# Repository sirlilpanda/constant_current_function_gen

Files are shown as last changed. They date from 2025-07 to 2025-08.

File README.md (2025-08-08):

# kicad project constant_current_function_gen


a cool table showing the workflow of all the kicad projects.
| project_name | DRC | ERC |
| --- | --- | --- |
| current_gen_class_ab | [❌](https://github.com/sirlilpanda/constant_current_function_gen/actions/runs/16821990167/attempts/1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)| [❌](https://github.com/sirlilpanda/constant_current_function_gen/actions/runs/16821990167/attempts/1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) | 
| current_gen | [✅](https://github.com/sirlilpanda/constant_current_function_gen/actions/runs/16821990167/attempts/1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)| [✅](https://github.com/sirlilpanda/constant_current_function_gen/actions/runs/16821990167/attempts/1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) | 

for a quick guide check [project setup](#project-setup)

This is a simple project template for new kicad projects. This template has some basic setup already completed such as workflows for auto creating all the things you forget when creating a kicad project such as:

| project_name | schematic | bom | bom report | gerbers |
| --- | --- | --- | --- | --- |
| [current_gen_class_ab](https://github.com/sirlilpanda/constant_current_function_gen/tree/main/./Hardware/current_gen_class_ab) | [current_gen_class_ab_schematic.pdf](https://github.com/sirlilpanda/constant_current_function_gen/tree/main/current_gen_class_ab_schematic.pdf) | [current_gen_class_ab_bill_of_materials.csv](https://github.com/sirlilpanda/constant_current_function_gen/tree/main/current_gen_class_ab_bill_of_materials.csv) | [current_gen_class_ab_bom_report.md](https://github.com/sirlilpanda/constant_current_function_gen/tree/main/current_gen_class_ab_bom_report.md) | [current_gen_class_ab_grbr.zip](https://github.com/sirlilpanda/constant_current_function_gen/tree/main/current_gen_class_ab_gerber.zip) |
| [current_gen](https://github.com/sirlilpanda/constant_current_function_gen/tree/main/./Hardware/current_gen) | [current_gen_schematic.pdf](https://github.com/sirlilpanda/constant_current_function_gen/tree/main/current_gen_schematic.pdf) | [current_gen_bill_of_materials.csv](https://github.com/sirlilpanda/constant_current_function_gen/tree/main/current_gen_bill_of_materials.csv) | [current_gen_bom_report.md](https://github.com/sirlilpanda/constant_current_function_gen/tree/main/current_gen_bom_report.md) | [current_gen_grbr.zip](https://github.com/sirlilpanda/constant_current_function_gen/tree/main/current_gen_gerber.zip) |

This workflow will also run the design rules check on the PCB and schematic to ensure that you upload a working PCB. These reports are uploaded as summaries within the github [actions tab](https://github.com/sirlilpanda/constant_current_function_gen/actions/runs/16821990167). This template has a simple schematic PCB in it (because DRC fails on an empty PCB). Shown below is the example PCB.

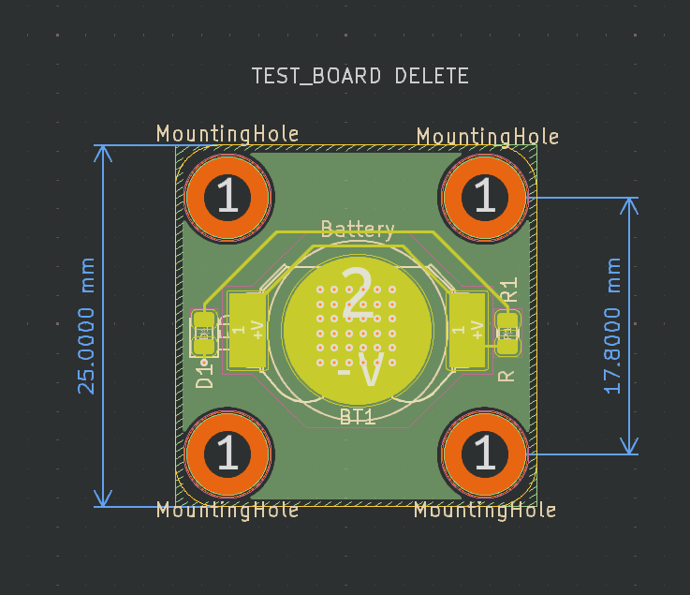
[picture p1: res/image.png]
example pcb with battery diode and resistor


besides from that the project also has:

- common predefined trace widths
- smallest vias size [JLCPBC allows](https://jlcpcb.com/capabilities/Capabilities#Drilling)
- custom net colours in the schematic editor
    - `red` for +V
    - `blue` for -V
    - `grey` for ground

to create a repo from this template follow this [guide](https://docs.github.com/en/repositories/creating-and-managing-repositories/creating-a-repository-from-a-template)

contained in this template are:
---
- `.github/` : all files relating to github actions and other admin see [here](https://docs.github.com/en/communities/setting-up-your-project-for-healthy-contributions) for more example of what can be placed in it
    - `report_processing` : where the python scripts are stored for processing the json report data from kicad
    - `report_templates` : where the template for said reports are stored
    - `workflows/` : this is where the github actions are kept
        - `main.yaml` : the main github action that will auto generate all files required and run DRC and ERC
    - `rename.py` : the script for renaming the project
- `hardware/` : this is where the kicad projects live note this can be changed
- `docs/` : this is where the generate docs are placed by default
    - `BOM/`     : where the bill of materials and price breakdown are kept
        - `bill_of_materials.csv`: the auto generated bom for the kicad project
        - `bom_report.md` : a report for the bill of materials
    - `template_schematic.pdf` : the schematic for the kicad project, auto generated by the github action
- `pcbs/` : this is where the auto generated gerbers for the kicad project are stored

- `res/` : where resources are stored for the README

- `.gitignore`: a slightly modified gitignore from the [standard one](https://github.com/github/gitignore/blob/main/KiCad.gitignore)

- `project_settings.yaml` : where the settings for this project is stored

- `README.md` : this file, suggest you change this one creating your project

## project settings
there are currently very few project settings that can be changed (will will be change in the future) these are:
| setting | description |
| --- | --- |
| has_been_set_up | a flag to tell the setup action if the project has been set up |
| project_name | the name of the project, this will be set to the name of the repo |
| production_formats | the output production format for the PCBs |
| dynamic_read_me | allow the readme to be updated using the given template |
| bom_template_path | the template used to write the bom report files |
| erc_report_template_path | the template used to write the erc report files |
| drc_report_template_path | the template used to write the drc report files |
| readme_template_path | the template used to write projects readme |
| schematic_output_name | the name suffix of the generated schematics |
| bom_csv_output_name | the name suffix of the generated bom csv file |
| bom_report_output_name | the name suffix of the generated bom report |
| production_file_output_name | the name suffix of the generated production file |
| schematic_output_path | the output path of the generated schematics files |
| bom_csv_output_path | the output path of the generated bom csv file |
| bom_report_output_path | the output path of the generated bom report |
| production_file_output_path | the output path of the generated production file |

## project setup

### creating a new repo with the template

creating a new template from a repo is simple:

1. click on the button in the top right hand corner called `use this template`
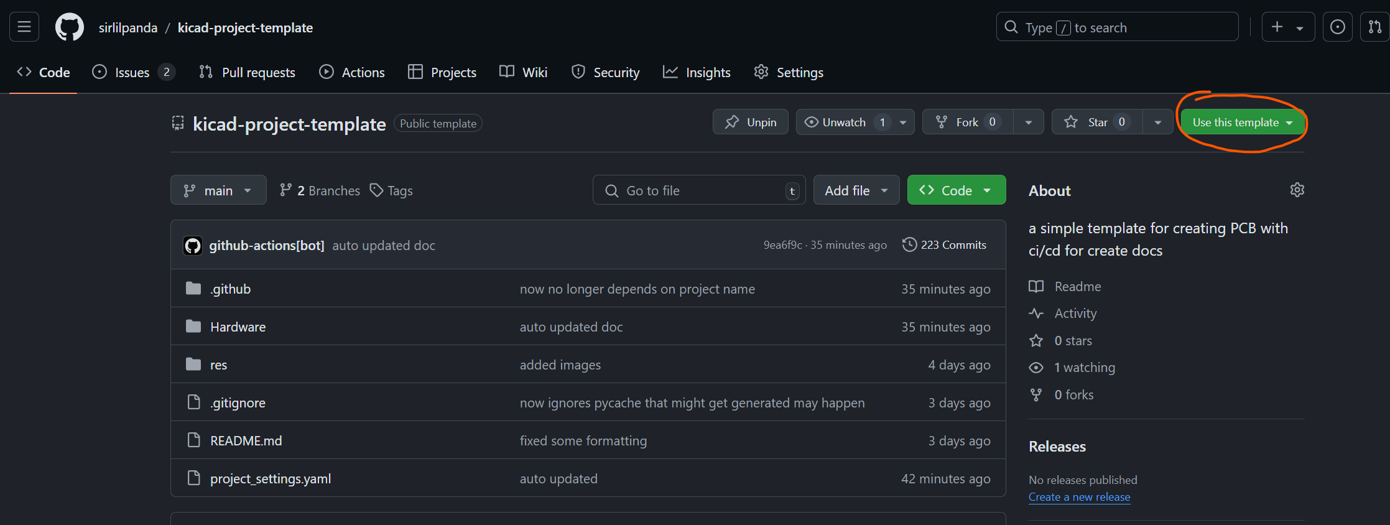
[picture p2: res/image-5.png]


2. when the drop down menu appears click on `create a new repository`
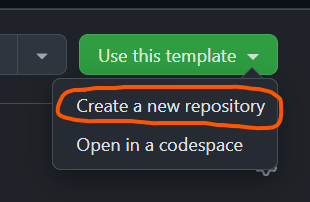
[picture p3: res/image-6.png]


3. once you click you will be brought to this page, note that the repo name you choose here will be the name that you kicad project is called.
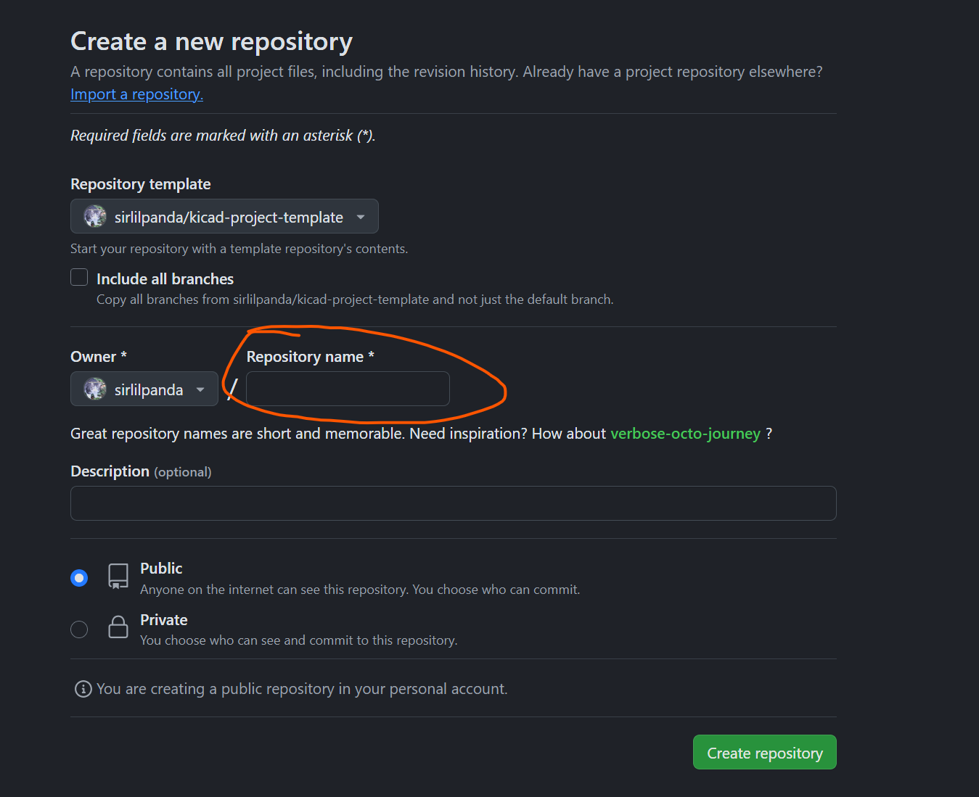
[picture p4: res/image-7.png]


after these steps you then need to configure the repo settings to do their magic see [configuring repo settings](#configuring-repo-settings) for what to do next.

### configuring repo settings

once you have created a new repo with the template, you ill have to configure the github action settings. this is because you will get an error that looks something along these lines:
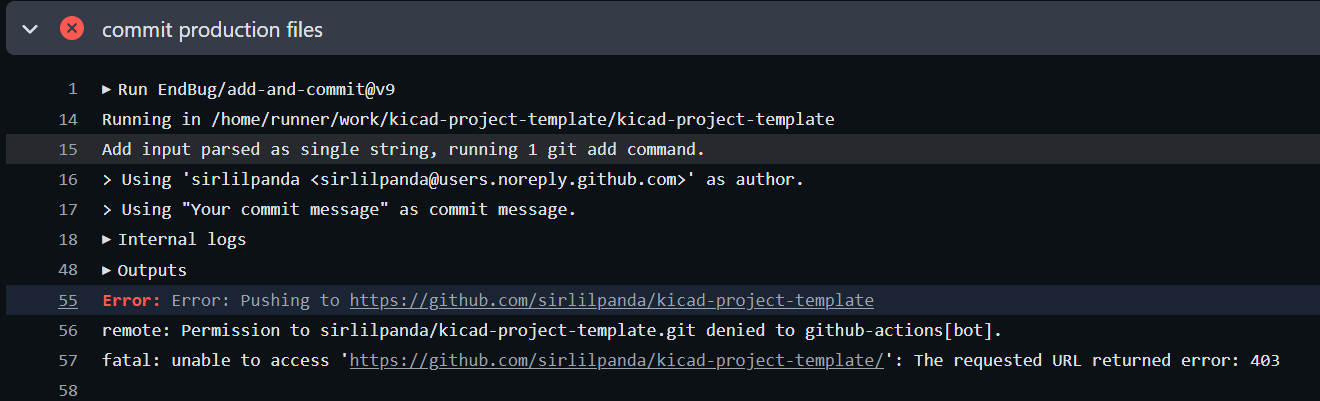
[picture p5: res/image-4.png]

where the action can not commit the changes due to not having permissions follow these steps:
1. open the repo setting
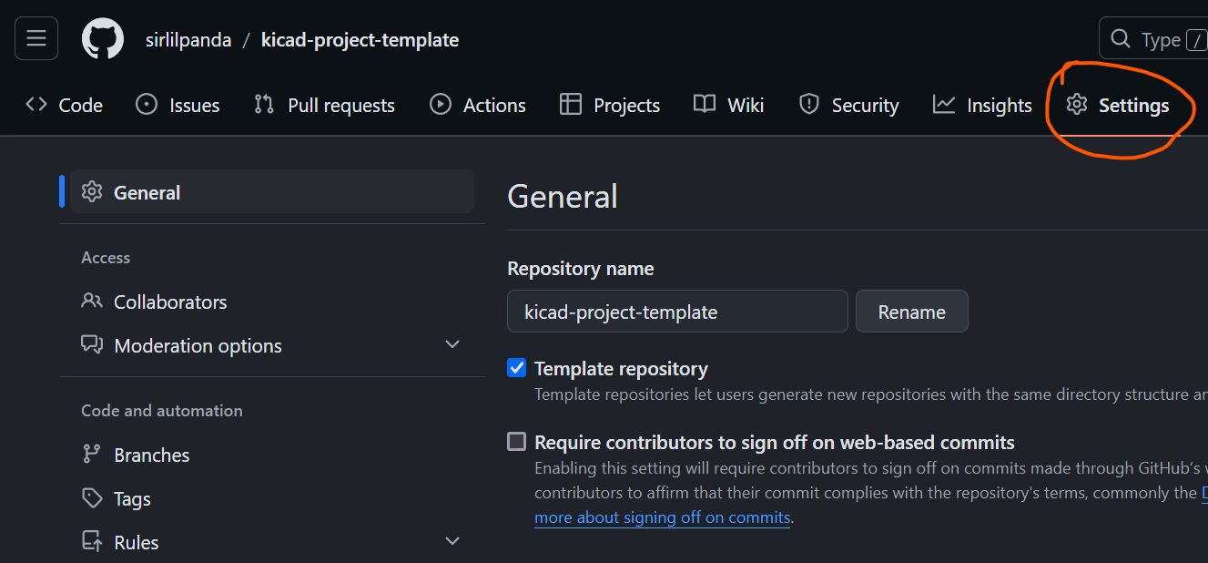
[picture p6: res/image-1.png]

2. then head in to actions : General
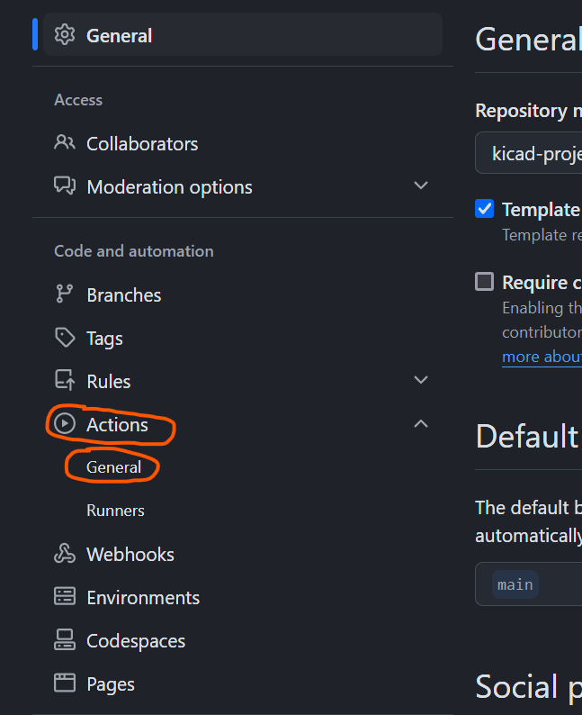
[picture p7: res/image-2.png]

3. then scroll down to workflow permissions and ensure that both
    `Read and write permissions` and `Allow GitHub Actions to create and approve pull requests` are ticked as seen below
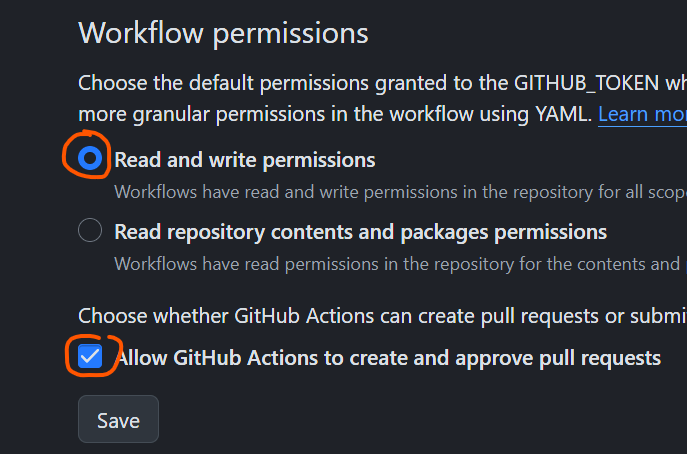
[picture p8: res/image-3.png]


this should fix the problem if not, go harass stack overflow they need it
Once all of these steps have been followed the workflow should be passing, however the `README.md` will only update on the next push request.

## editing the readme

As this repo can and will automatically update the repo corresponding to the given readme template. If you dont want to use this you can always disable this by setting the `dynamic_read_me` to `false`. but if you want some very cool features like auto updating tables to show what projects are passing the rules check or simple links to parts of your directory. then have a look at the template readme and learn [mustache](https://mustache.github.io/)

## improvements

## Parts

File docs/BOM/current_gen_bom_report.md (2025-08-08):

# 📄 BOM for current_gen_bill_of_material 📄

report created at 04:35:27.789618 on 08-08-2025.

current_gen_bill_of_material has a total of 28 parts with a cost of $0.

| Reference | Value | Quantity | part number | cost |
| --- | ----- | --- | --- | ---- |
| C1 | 1u | 1 |  | $0 |
| D1 | BZT52Bxx | 1 | Diode_SMD:D_SOD-123F | $0 |
| F1 | Fuse | 1 |  | $0 |
| J1 | Conn_Coaxial | 1 |  | $0 |
| J2 | Conn_Coaxial | 1 |  | $0 |
| J3 | Jack-DC | 1 |  | $0 |
| J4 | Conn_Coaxial | 1 |  | $0 |
| JP1 | Jumper_2_Open | 1 |  | $0 |
| Q1 | NPN | 1 |  | $0 |
| Q2 | NPN | 1 |  | $0 |
| Q3 | NPN | 1 |  | $0 |
| Q4 | NPN | 1 |  | $0 |
| Q5 | NPN | 1 |  | $0 |
| Q6 | NPN | 1 |  | $0 |
| Q7 | NPN | 1 |  | $0 |
| Q8 | NPN | 1 |  | $0 |
| Q9 | NPN | 1 |  | $0 |
| Q10 | NPN | 1 |  | $0 |
| Q11 | NPN | 1 |  | $0 |
| Q12 | NPN | 1 |  | $0 |
| Q13 | BSP129 | 1 | Package_TO_SOT_SMD:SOT-223-3_TabPin2 | $0 |
| R1 | 100R | 1 |  | $0 |
| R2 | 330R | 1 |  | $0 |
| R3 | 22R | 1 |  | $0 |
| R4 | 1k | 1 |  | $0 |
| R5 | 10k | 1 |  | $0 |
| R6 | 10m | 1 |  | $0 |
| U1 | OPA2673 | 1 | Package_DFN_QFN:Texas_RSA_VQFN-16-1EP_4x4mm_P0.65mm_EP2.7x2.7mm | $0 |
|  | total | 28 | total | $0 |

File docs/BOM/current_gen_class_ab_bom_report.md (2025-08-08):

# 📄 BOM for current_gen_class_ab_bill_of_material 📄

report created at 04:35:23.391193 on 08-08-2025.

current_gen_class_ab_bill_of_material has a total of 67 parts with a cost of $0.

| Reference | Value | Quantity | part number | cost |
| --- | ----- | --- | --- | ---- |
| C1 | 1u | 1 | Capacitor_SMD:C_0805_2012Metric | $0 |
| C2 | 1u | 1 | Capacitor_SMD:C_0805_2012Metric | $0 |
| C3 | 1u | 1 | Capacitor_SMD:C_0805_2012Metric | $0 |
| C4 | 1u | 1 | Capacitor_SMD:C_0805_2012Metric | $0 |
| C5 | 1u | 1 | Capacitor_SMD:C_0805_2012Metric | $0 |
| D1 | D_Zener | 1 | Diode_SMD:D_SOD-123 | $0 |
| D2 | D_Zener | 1 | Diode_SMD:D_SOD-123 | $0 |
| D3 | BAV99 | 1 | Package_TO_SOT_SMD:SOT-23 | $0 |
| D4 | LED | 1 | Diode_SMD:D_0603_1608Metric | $0 |
| D5 | LED | 1 | Diode_SMD:D_0603_1608Metric | $0 |
| D6 | LED | 1 | Diode_SMD:D_0603_1608Metric | $0 |
| D7 | LED | 1 | Diode_SMD:D_0603_1608Metric | $0 |
| F1 | Fuse | 1 | Fuse:Fuseholder_Clip-5x20mm_Bel_FC-203-22_Lateral_P17.80x5.00mm_D1.17mm_Horizontal | $0 |
| F2 | Fuse | 1 | Fuse:Fuseholder_Clip-5x20mm_Bel_FC-203-22_Lateral_P17.80x5.00mm_D1.17mm_Horizontal | $0 |
| F4 | Fuse | 1 | Fuse:Fuseholder_Clip-5x20mm_Bel_FC-203-22_Lateral_P17.80x5.00mm_D1.17mm_Horizontal | $0 |
| F5 | Fuse | 1 | Fuse:Fuseholder_Clip-5x20mm_Bel_FC-203-22_Lateral_P17.80x5.00mm_D1.17mm_Horizontal | $0 |
| J1 | Conn_Coaxial | 1 | Connector_Coaxial:BNC_TEConnectivity_1478035_Horizontal | $0 |
| J2 | Conn_Coaxial | 1 | Connector_Coaxial:BNC_TEConnectivity_1478035_Horizontal | $0 |
| J3 | Conn_01x01_Socket | 1 | Connector:Banana_Jack_1Pin | $0 |
| J4 | Conn_01x01_Socket | 1 | Connector:Banana_Jack_1Pin | $0 |
| J5 | Conn_01x01_Socket | 1 | Connector:Banana_Jack_1Pin | $0 |
| J6 | Conn_01x01_Socket | 1 | Connector:Banana_Jack_1Pin | $0 |
| J7 | Conn_01x01_Socket | 1 | Connector:Banana_Jack_1Pin | $0 |
| JP1 | Jumper_2_Open | 1 | Jumper:SolderJumper-2_P1.3mm_Open_TrianglePad1.0x1.5mm | $0 |
| JP2 | Jumper_2_Open | 1 | Jumper:SolderJumper-2_P1.3mm_Open_TrianglePad1.0x1.5mm | $0 |
| JP3 | Jumper_2_Open | 1 | Jumper:SolderJumper-2_P1.3mm_Open_TrianglePad1.0x1.5mm | $0 |
| JP4 | Jumper_2_Open | 1 | Jumper:SolderJumper-2_P1.3mm_Open_TrianglePad1.0x1.5mm | $0 |
| JP5 | Jumper_2_Open | 1 | Jumper:SolderJumper-2_P1.3mm_Open_TrianglePad1.0x1.5mm | $0 |
| Q1 | PMOS | 1 | Package_TO_SOT_THT:TO-220-3_Horizontal_TabDown | $0 |
| Q2 | NMOS | 1 | Package_TO_SOT_THT:TO-220-3_Horizontal_TabDown | $0 |
| Q3 | NMOS | 1 | Package_TO_SOT_THT:TO-220-3_Horizontal_TabDown | $0 |
| Q4 | PMOS | 1 | Package_TO_SOT_THT:TO-220-3_Horizontal_TabDown | $0 |
| R1 | 50 | 1 | Resistor_THT:R_Axial_DIN0309_L9.0mm_D3.2mm_P12.70mm_Horizontal | $0 |
| R2 | 92k | 1 | Resistor_SMD:R_0603_1608Metric | $0 |
| R3 | 92k | 1 | Resistor_SMD:R_0603_1608Metric | $0 |
| R4 | 100k | 1 | Resistor_SMD:R_0603_1608Metric | $0 |
| R5 | 1k | 1 | Resistor_SMD:R_0603_1608Metric | $0 |
| R6 | 1k | 1 | Resistor_SMD:R_0603_1608Metric | $0 |
| R7 | 100k | 1 | Resistor_SMD:R_0603_1608Metric | $0 |
| R8 | 100k | 1 | Resistor_SMD:R_0603_1608Metric | $0 |
| R9 | 1k | 1 | Resistor_SMD:R_0603_1608Metric | $0 |
| R10 | 1k | 1 | Resistor_SMD:R_0603_1608Metric | $0 |
| R11 | 100k | 1 | Resistor_SMD:R_0603_1608Metric | $0 |
| R12 | 92k | 1 | Resistor_SMD:R_0603_1608Metric | $0 |
| R13 | 92k | 1 | Resistor_SMD:R_0603_1608Metric | $0 |
| R14 | 10 | 1 | Resistor_SMD:R_0603_1608Metric | $0 |
| R15 | 10 | 1 | Resistor_SMD:R_0603_1608Metric | $0 |
| R16 | 5R | 1 | Package_TO_SOT_THT:TO-220-2_Horizontal_TabDown | $0 |
| R17 | 5R | 1 | Package_TO_SOT_THT:TO-220-2_Horizontal_TabDown | $0 |
| R18 | 10k | 1 | Potentiometer_THT:Potentiometer_Bourns_3296W_Vertical | $0 |
| R19 | 10k | 1 | Potentiometer_THT:Potentiometer_Bourns_3296W_Vertical | $0 |
| R20 | 92k | 1 | Resistor_SMD:R_0603_1608Metric | $0 |
| R21 | 92k | 1 | Resistor_SMD:R_0603_1608Metric | $0 |
| R22 | 1k | 1 | Resistor_SMD:R_0603_1608Metric | $0 |
| R23 | 1k | 1 | Resistor_SMD:R_0603_1608Metric | $0 |
| R24 | 1k | 1 | Resistor_SMD:R_0603_1608Metric | $0 |
| R25 | 27k | 1 | Resistor_SMD:R_0603_1608Metric | $0 |
| R26 | 1k | 1 | Resistor_SMD:R_0603_1608Metric | $0 |
| R27 | 27k | 1 | Resistor_SMD:R_0603_1608Metric | $0 |
| R28 | 1k | 1 | Resistor_SMD:R_0603_1608Metric | $0 |
| R29 | 1k | 1 | Resistor_SMD:R_0603_1608Metric | $0 |
| RV1 | 10k | 1 | footprints:POT_P120PK-x25_TTE | $0 |
| RV2 | 10k | 1 | footprints:POT_P120PK-x25_TTE | $0 |
| RV3 | 10k | 1 | Potentiometer_THT:Potentiometer_Bourns_PTV09A-1_Single_Vertical | $0 |
| RV4 | 10k | 1 | Potentiometer_THT:Potentiometer_Bourns_PTV09A-1_Single_Vertical | $0 |
| U1 | Opamp_Dual | 1 | Package_SO:SOIC-8-1EP_3.9x4.9mm_P1.27mm_EP2.29x3mm_ThermalVias | $0 |
| U2 | Opamp_Dual | 1 | Package_SO:SOIC-8-1EP_3.9x4.9mm_P1.27mm_EP2.29x3mm_ThermalVias | $0 |
|  | total | 67 | total | $0 |

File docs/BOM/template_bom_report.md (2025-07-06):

# 📄 BOM for template_bill_of_material 📄

report created at 00:00:12.772009 on 02-07-2025.

template_bill_of_material has a total of 3 parts with a cost of $0.

| Reference | Value | Quantity | part number | cost |
| --- | ----- | --- | --- | ---- |
| BT1 | Battery | 1 | Battery:BatteryHolder_LINX_BAT-HLD-012-SMT | $0 |
| D1 | LED | 1 | LED_SMD:LED_0805_2012Metric | $0 |
| R1 | R | 1 | Resistor_SMD:R_0805_2012Metric | $0 |
|  | total | 3 | total | $0 |

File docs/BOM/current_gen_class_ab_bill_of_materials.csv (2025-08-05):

Refs | Value | Footprint | Qty | DNP
C1 | 1u | Capacitor_SMD:C_0805_2012Metric | 1
C2 | 1u | Capacitor_SMD:C_0805_2012Metric | 1
C3 | 1u | Capacitor_SMD:C_0805_2012Metric | 1
C4 | 1u | Capacitor_SMD:C_0805_2012Metric | 1
C5 | 1u | Capacitor_SMD:C_0805_2012Metric | 1
D1 | D_Zener | Diode_SMD:D_SOD-123 | 1
D2 | D_Zener | Diode_SMD:D_SOD-123 | 1
D3 | BAV99 | Package_TO_SOT_SMD:SOT-23 | 1
D4 | LED | Diode_SMD:D_0603_1608Metric | 1
D5 | LED | Diode_SMD:D_0603_1608Metric | 1
D6 | LED | Diode_SMD:D_0603_1608Metric | 1
D7 | LED | Diode_SMD:D_0603_1608Metric | 1
F1 | Fuse | Fuse:Fuseholder_Clip-5x20mm_Bel_FC-203-22_Lateral_P17.80x5.00mm_D1.17mm_Horizontal | 1
F2 | Fuse | Fuse:Fuseholder_Clip-5x20mm_Bel_FC-203-22_Lateral_P17.80x5.00mm_D1.17mm_Horizontal | 1
F4 | Fuse | Fuse:Fuseholder_Clip-5x20mm_Bel_FC-203-22_Lateral_P17.80x5.00mm_D1.17mm_Horizontal | 1
F5 | Fuse | Fuse:Fuseholder_Clip-5x20mm_Bel_FC-203-22_Lateral_P17.80x5.00mm_D1.17mm_Horizontal | 1
J1 | Conn_Coaxial | Connector_Coaxial:BNC_TEConnectivity_1478035_Horizontal | 1
J2 | Conn_Coaxial | Connector_Coaxial:BNC_TEConnectivity_1478035_Horizontal | 1
J3 | Conn_01x01_Socket | Connector:Banana_Jack_1Pin | 1
J4 | Conn_01x01_Socket | Connector:Banana_Jack_1Pin | 1
J5 | Conn_01x01_Socket | Connector:Banana_Jack_1Pin | 1
J6 | Conn_01x01_Socket | Connector:Banana_Jack_1Pin | 1
J7 | Conn_01x01_Socket | Connector:Banana_Jack_1Pin | 1
JP1 | Jumper_2_Open | Jumper:SolderJumper-2_P1.3mm_Open_TrianglePad1.0x1.5mm | 1
JP2 | Jumper_2_Open | Jumper:SolderJumper-2_P1.3mm_Open_TrianglePad1.0x1.5mm | 1
JP3 | Jumper_2_Open | Jumper:SolderJumper-2_P1.3mm_Open_TrianglePad1.0x1.5mm | 1
JP4 | Jumper_2_Open | Jumper:SolderJumper-2_P1.3mm_Open_TrianglePad1.0x1.5mm | 1
JP5 | Jumper_2_Open | Jumper:SolderJumper-2_P1.3mm_Open_TrianglePad1.0x1.5mm | 1
Q1 | PMOS | Package_TO_SOT_THT:TO-220-3_Horizontal_TabDown | 1
Q2 | NMOS | Package_TO_SOT_THT:TO-220-3_Horizontal_TabDown | 1
Q3 | NMOS | Package_TO_SOT_THT:TO-220-3_Horizontal_TabDown | 1
Q4 | PMOS | Package_TO_SOT_THT:TO-220-3_Horizontal_TabDown | 1
R1 | 50 | Resistor_THT:R_Axial_DIN0309_L9.0mm_D3.2mm_P12.70mm_Horizontal | 1
R2 | 92k | Resistor_SMD:R_0603_1608Metric | 1
R3 | 92k | Resistor_SMD:R_0603_1608Metric | 1
R4 | 100k | Resistor_SMD:R_0603_1608Metric | 1
R5 | 1k | Resistor_SMD:R_0603_1608Metric | 1
R6 | 1k | Resistor_SMD:R_0603_1608Metric | 1
R7 | 100k | Resistor_SMD:R_0603_1608Metric | 1
R8 | 100k | Resistor_SMD:R_0603_1608Metric | 1
R9 | 1k | Resistor_SMD:R_0603_1608Metric | 1
R10 | 1k | Resistor_SMD:R_0603_1608Metric | 1
R11 | 100k | Resistor_SMD:R_0603_1608Metric | 1
R12 | 92k | Resistor_SMD:R_0603_1608Metric | 1
R13 | 92k | Resistor_SMD:R_0603_1608Metric | 1
R14 | 10 | Resistor_SMD:R_0603_1608Metric | 1
R15 | 10 | Resistor_SMD:R_0603_1608Metric | 1
R16 | 5R | Package_TO_SOT_THT:TO-220-2_Horizontal_TabDown | 1
R17 | 5R | Package_TO_SOT_THT:TO-220-2_Horizontal_TabDown | 1
R18 | 10k | Potentiometer_THT:Potentiometer_Bourns_3296W_Vertical | 1
R19 | 10k | Potentiometer_THT:Potentiometer_Bourns_3296W_Vertical | 1
R20 | 92k | Resistor_SMD:R_0603_1608Metric | 1
R21 | 92k | Resistor_SMD:R_0603_1608Metric | 1
R22 | 1k | Resistor_SMD:R_0603_1608Metric | 1
R23 | 1k | Resistor_SMD:R_0603_1608Metric | 1
R24 | 1k | Resistor_SMD:R_0603_1608Metric | 1
R25 | 27k | Resistor_SMD:R_0603_1608Metric | 1
R26 | 1k | Resistor_SMD:R_0603_1608Metric | 1
R27 | 27k | Resistor_SMD:R_0603_1608Metric | 1
R28 | 1k | Resistor_SMD:R_0603_1608Metric | 1
R29 | 1k | Resistor_SMD:R_0603_1608Metric | 1
RV1 | 10k | footprints:POT_P120PK-x25_TTE | 1
RV2 | 10k | footprints:POT_P120PK-x25_TTE | 1
RV3 | 10k | Potentiometer_THT:Potentiometer_Bourns_PTV09A-1_Single_Vertical | 1
RV4 | 10k | Potentiometer_THT:Potentiometer_Bourns_PTV09A-1_Single_Vertical | 1
U1 | Opamp_Dual | Package_SO:SOIC-8-1EP_3.9x4.9mm_P1.27mm_EP2.29x3mm_ThermalVias | 1
U2 | Opamp_Dual | Package_SO:SOIC-8-1EP_3.9x4.9mm_P1.27mm_EP2.29x3mm_ThermalVias | 1

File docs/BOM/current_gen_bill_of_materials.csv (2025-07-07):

Refs | Value | Footprint | Qty | DNP
C1 | 1u |  | 1
D1 | BZT52Bxx | Diode_SMD:D_SOD-123F | 1
F1 | Fuse |  | 1
J1 | Conn_Coaxial |  | 1
J2 | Conn_Coaxial |  | 1
J3 | Jack-DC |  | 1
J4 | Conn_Coaxial |  | 1
JP1 | Jumper_2_Open |  | 1
Q1 | NPN |  | 1
Q2 | NPN |  | 1
Q3 | NPN |  | 1
Q4 | NPN |  | 1
Q5 | NPN |  | 1
Q6 | NPN |  | 1
Q7 | NPN |  | 1
Q8 | NPN |  | 1
Q9 | NPN |  | 1
Q10 | NPN |  | 1
Q11 | NPN |  | 1
Q12 | NPN |  | 1
Q13 | BSP129 | Package_TO_SOT_SMD:SOT-223-3_TabPin2 | 1
R1 | 100R |  | 1
R2 | 330R |  | 1
R3 | 22R |  | 1
R4 | 1k |  | 1
R5 | 10k |  | 1
R6 | 10m |  | 1
U1 | OPA2673 | Package_DFN_QFN:Texas_RSA_VQFN-16-1EP_4x4mm_P0.65mm_EP2.7x2.7mm | 1

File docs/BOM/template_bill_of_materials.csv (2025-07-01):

Refs | Value | Footprint | Qty | DNP
BT1 | Battery | Battery:BatteryHolder_LINX_BAT-HLD-012-SMT | 1
D1 | LED | LED_SMD:LED_0805_2012Metric | 1
R1 | R | Resistor_SMD:R_0805_2012Metric | 1

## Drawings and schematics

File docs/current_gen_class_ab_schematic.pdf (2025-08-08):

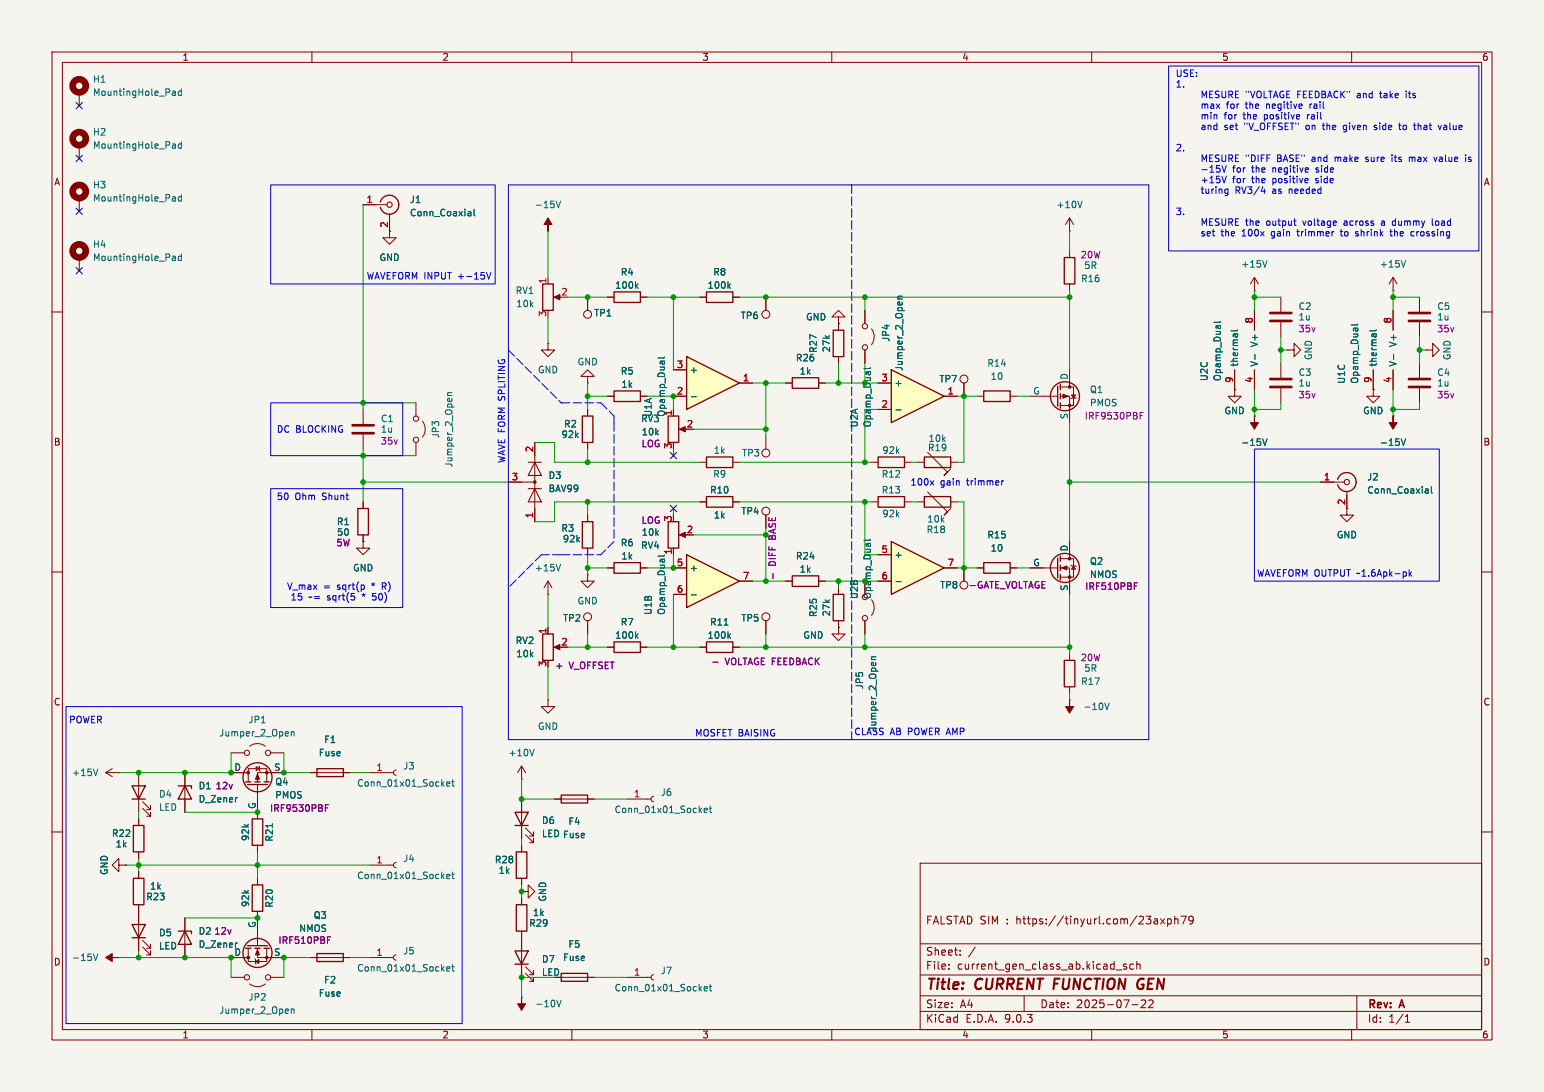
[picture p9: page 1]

CLASS AB POWER AMP

Id: 1/1 Title: CURRENT FUNCTION GEN

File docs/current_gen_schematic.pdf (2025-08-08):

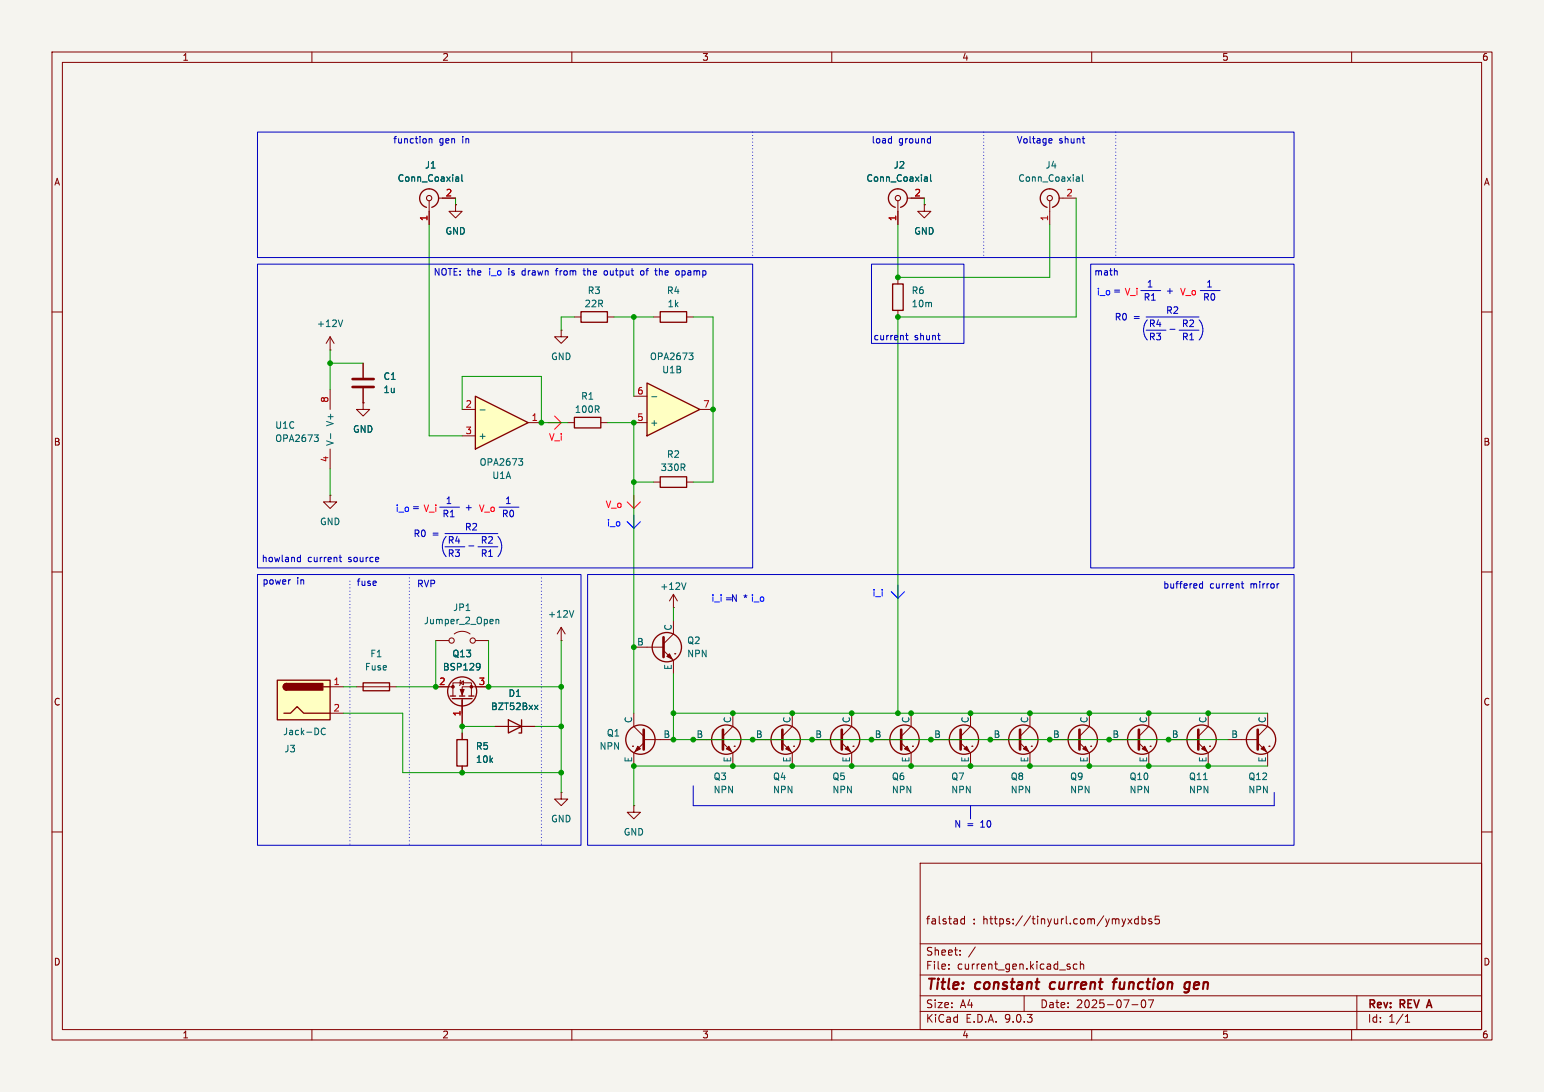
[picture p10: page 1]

File: current_gen.kicad_sch Sheet: /
Id: 1/1 Title: constant current function gen

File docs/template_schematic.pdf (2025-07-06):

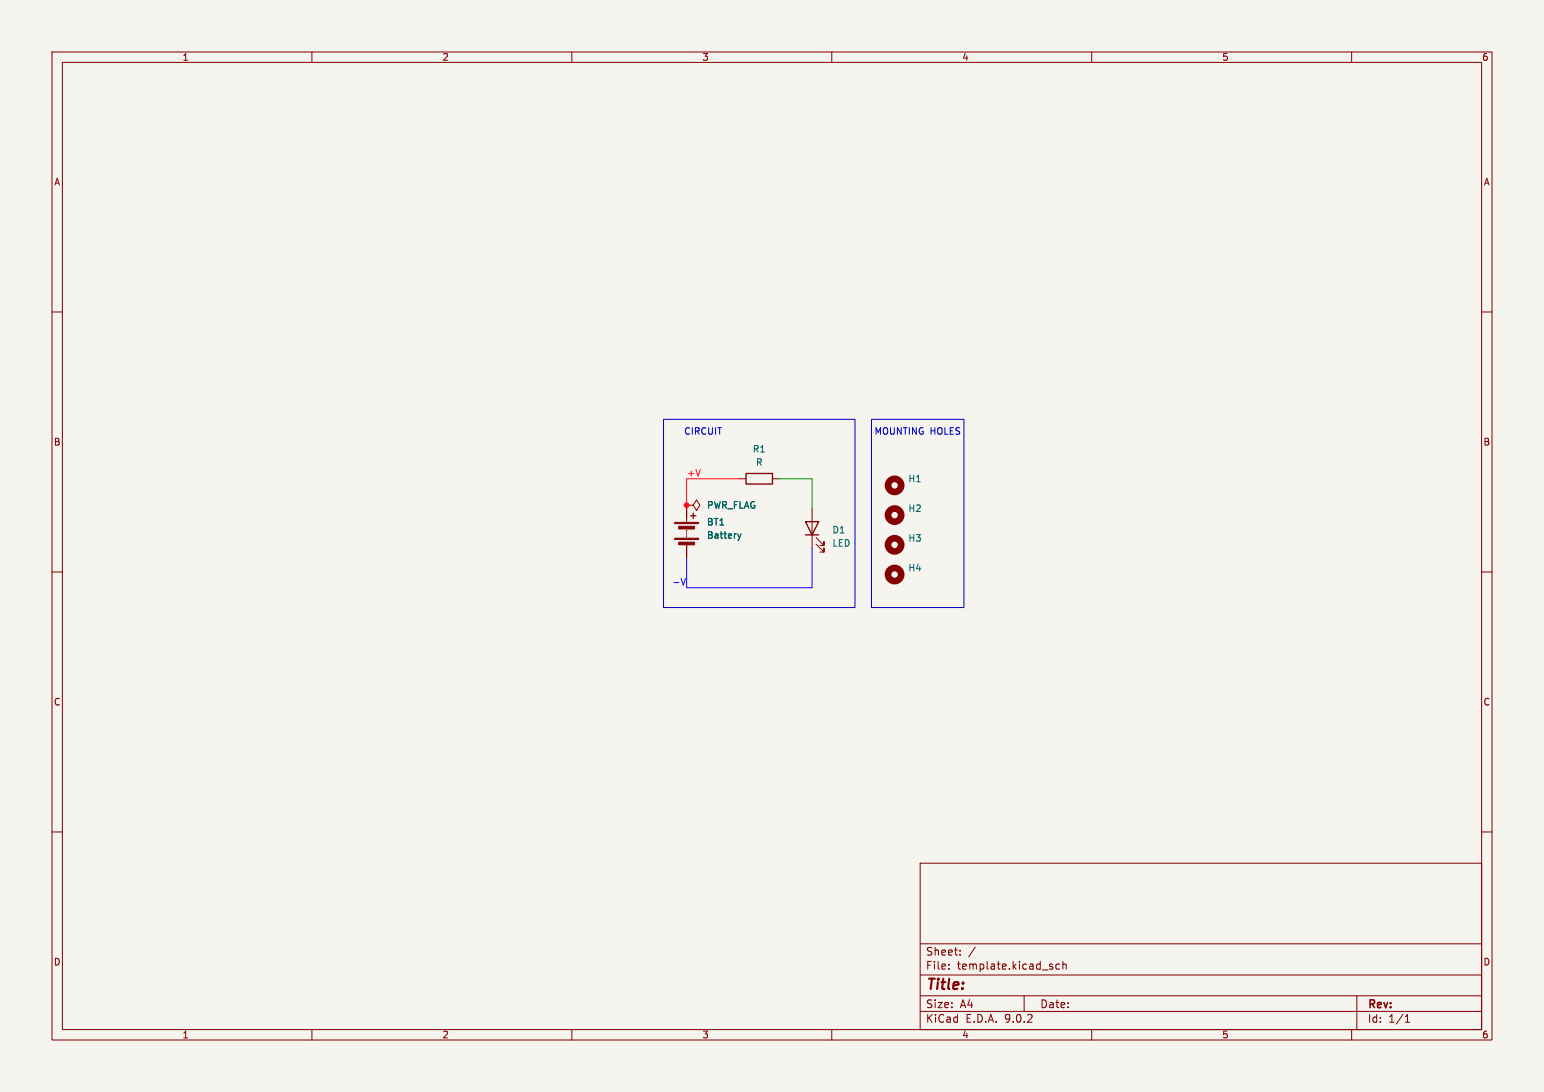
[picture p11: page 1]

Id: 1/1 Title: File: template.kicad_sch Sheet: / H4 D1
LED

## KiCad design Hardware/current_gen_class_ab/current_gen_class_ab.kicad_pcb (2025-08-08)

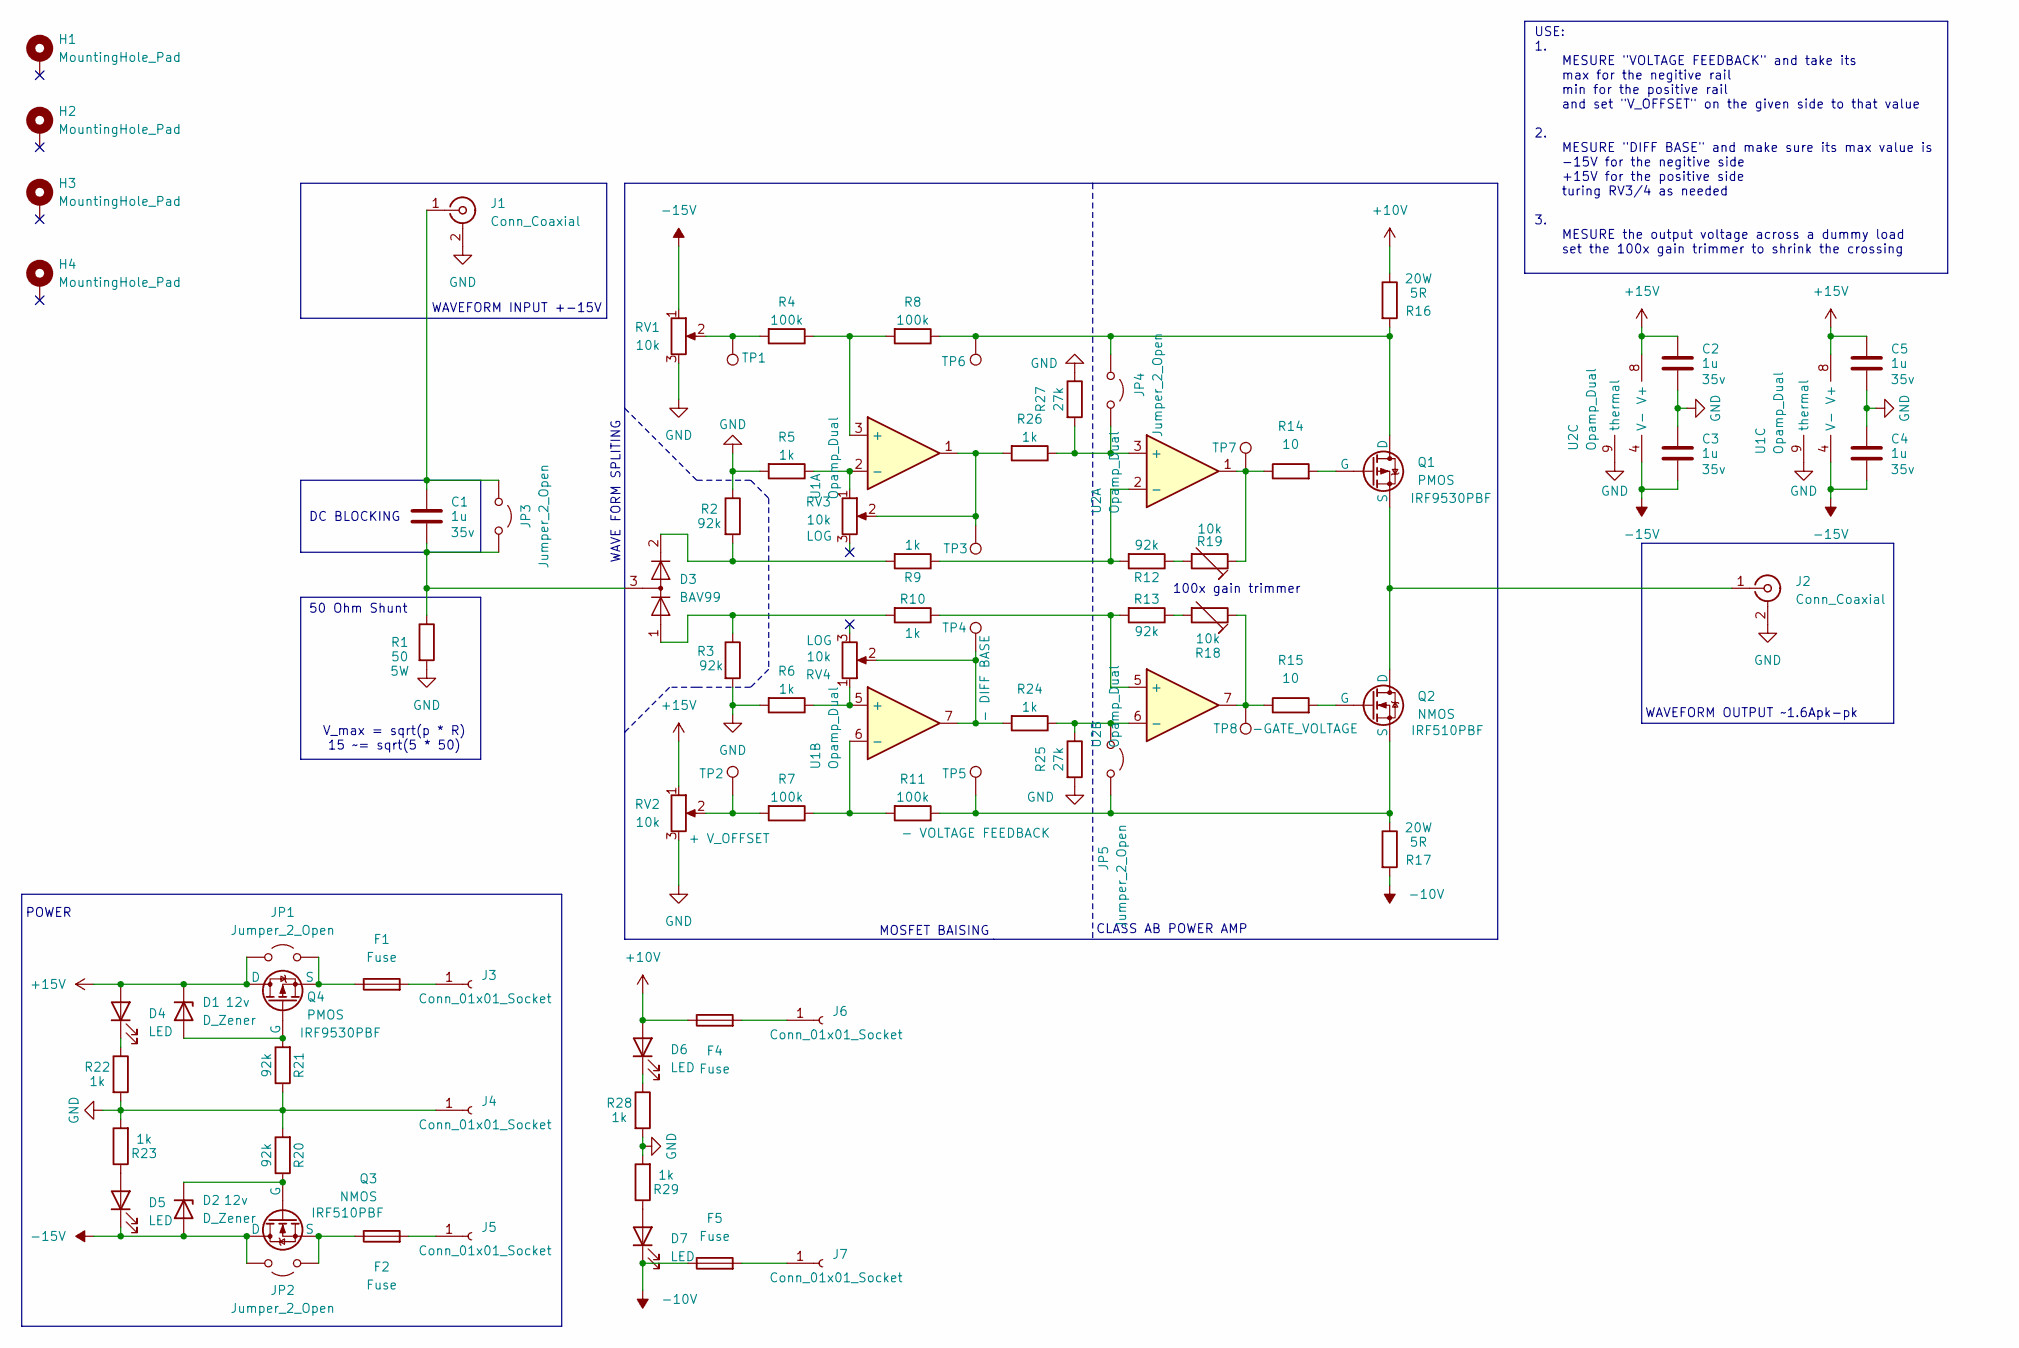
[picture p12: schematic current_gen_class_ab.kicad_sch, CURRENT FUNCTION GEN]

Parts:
C1, C2, C3, C4, C5: 1u; C_0805_2012Metric
D1, D2: D_Zener; D_SOD-123
D3: BAV99; SOT-23; Manufactor Part Number BAV99
D4, D5, D6, D7: LED; D_0603_1608Metric
F1, F2, F4, F5: Fuse; Fuseholder_Clip-5x20mm_Bel_FC-203-22_Lateral_P17.80x5.00mm_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
H1, H2, H3, H4: MountingHole_Pad; MountingHole_3.2mm_M3_DIN965_Pad
J1, J2: Conn_Coaxial; BNC_TEConnectivity_1478035_Horizontal
J3, J4, J5, J6, J7: Conn_01x01_Socket; Banana_Jack_1Pin
JP1, JP2, JP3, JP4, JP5: Jumper_2_Open; SolderJumper-2_P1.3mm_Open_TrianglePad1.0x1.5mm
Q1, Q4: PMOS; TO-220-3_Horizontal_TabDown
Q2, Q3: NMOS; TO-220-3_Horizontal_TabDown
R1: 50; R_Axial_DIN0309_L9.0mm_D3.2mm_P12.70mm_Horizontal
R2, R3, R12, R13, R20, R21: 92k; R_0603_1608Metric
R4, R7, R8, R11: 100k; R_0603_1608Metric
R5, R6, R9, R10, R22, R23, R24, R26, R28, R29: 1k; R_0603_1608Metric
R14, R15: 10; R_0603_1608Metric
R16, R17: 5R; TO-220-2_Horizontal_TabDown
R18, R19: 10k; Potentiometer_Bourns_3296W_Vertical
R25, R27: 27k; R_0603_1608Metric
RV1, RV2: 10k; POT_P120PK-x25_TTE
RV3, RV4: 10k; Potentiometer_Bourns_PTV09A-1_Single_Vertical
TP1, TP2, TP3, TP4, TP5, TP6, TP7, TP8: TestPoint; TestPoint_Bridge_Pitch2.54mm_Drill1.3mm
U1, U2: Opamp_Dual; SOIC-8-1EP_3.9x4.9mm_P1.27mm_EP2.29x3mm_ThermalVias

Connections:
+10V: D6.2 (A), F4.1, R16.1
+15V: C2.2, C5.2, D1.1 (K), D4.2 (A), JP1.1 (A), Q4.1 (D), RV2.1, U1.8 (V+), U2.8 (V+)
-10V: D7.1 (K), F5.1, R17.2
-15V: C3.1, C4.1, D2.2 (A), D5.1 (K), JP2.2 (B), Q3.1 (D), RV1.1, U1.4 (V-), U2.4 (V-)
GND: C2.1, C3.2, C4.2, C5.1, J1.2 (Ext), J2.2 (Ext), J4.1, R1.2, R2.1, R3.2, R5.2, R6.2, R20.2, R21.1, R22.2, R23.2, R25.2, R27.1, R28.2, R29.2, RV1.3, RV2.3, U1.9 (thermal), U2.9 (thermal)
unnamed: D1.2 (A), Q4.2 (G), R21.2
unnamed: D2.1 (K), Q3.2 (G), R20.1
unnamed: D3.2 (A), R2.2, R9.2
unnamed: D3.1 (K), R3.1, R10.2
unnamed: D4.1 (K), R22.1
unnamed: D5.2 (A), R23.1
unnamed: D6.1 (K), R28.1
unnamed: D7.2 (A), R29.1
unnamed: C1.2, J1.1 (In), JP3.1 (A)
unnamed: J2.1 (In), Q1.3 (S), Q2.1 (D)
unnamed: F1.2, J3.1
unnamed: F2.2, J5.1
unnamed: F4.2, J6.1
unnamed: F5.2, J7.1
unnamed: F1.1, JP1.2 (B), Q4.3 (S)
unnamed: F2.1, JP2.1 (A), Q3.3 (S)
unnamed: C1.1, D3.3 (K), JP3.2 (B), R1.1
unnamed: JP4.1 (A), Q1.1 (D), R8.1, R16.2, TP6.1
unnamed: JP4.2 (B), R26.1, R27.2, U2.3 (+)
unnamed: JP5.1 (A), R24.1, R25.1, U2.6 (-)
unnamed: JP5.2 (B), Q2.3 (S), R11.1, R17.1, TP5.1
unnamed: Q1.2 (G), R14.2
unnamed: Q2.2 (G), R15.2
unnamed: R4.2, RV1.2, TP1.1
unnamed: R7.2, RV2.2, TP2.1
unnamed: R12.1, R19.2
unnamed: R13.1, R18.2
unnamed: R14.1, R19.1, TP7.1, U2.1
unnamed: R15.1, R18.1, TP8.1, U2.7
unnamed: R24.2, RV4.2, TP4.1, U1.7
unnamed: R26.2, RV3.2, TP3.1, U1.1
unnamed: R4.1, R8.2, U1.3 (+)
unnamed: R5.1, RV3.1, U1.2 (-)
unnamed: R6.1, RV4.1, U1.5 (+)
unnamed: R7.1, R11.2, U1.6 (-)
unnamed: R9.1, R12.2, U2.2 (-)
unnamed: R10.1, R13.2, U2.5 (+)

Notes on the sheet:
MOSFET BAISING
WAVE FORM SPLITING
POWER
V_max = sqrt(p * R) 15 ~= sqrt(5 * 50)
WAVEFORM OUTPUT ~1.6Apk-pk
CLASS AB POWER AMP
100x gain trimmer
50 Ohm Shunt
DC BLOCKING
USE: 1. MESURE "VOLTAGE FEEDBACK" and take its max for the negitive rail min for the positive rail and set "V_OFFSET" on the given side to that value 2. MESURE "DIFF BASE" and make sure its max value is -15V for the negitive side +15V for the positive side turing RV3/4 as needed 3. MESURE the outpu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
WAVEFORM INPUT +-15V

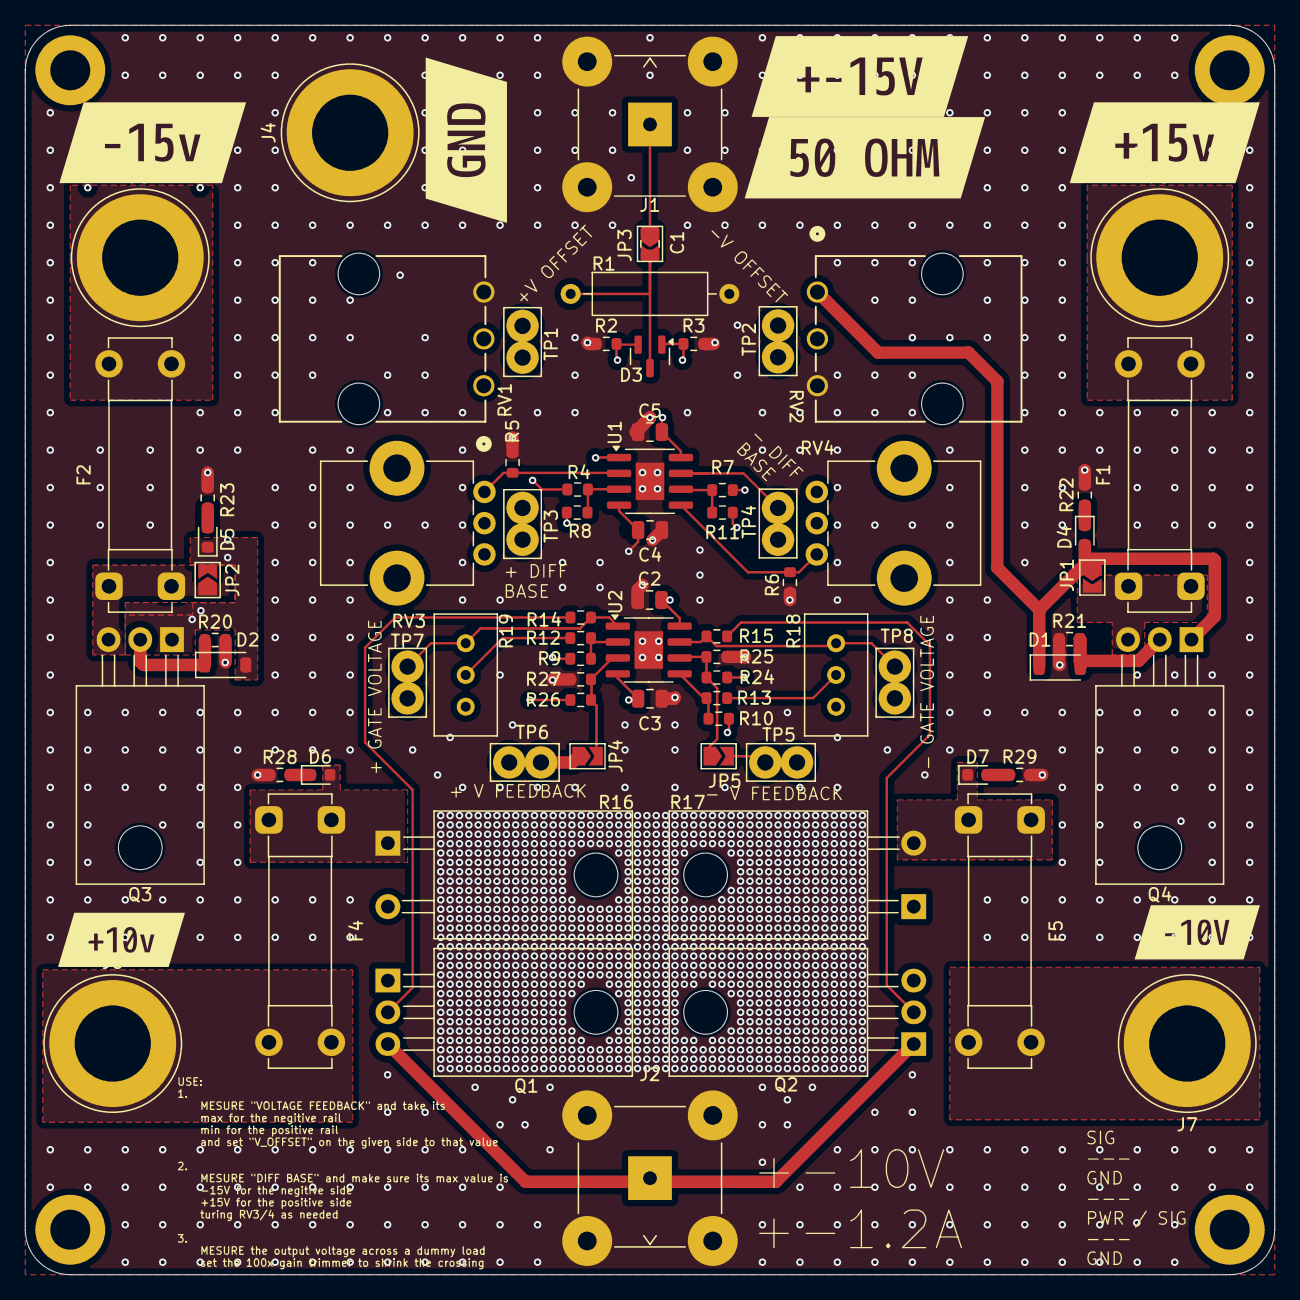
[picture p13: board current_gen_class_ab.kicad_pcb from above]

Board: 4 copper layers, 100.0 x 100.0 mm, 86 parts (0 on the bottom side), 42 nets.

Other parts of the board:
kibuzzard-68929C8D: G***; kibuzzard-68929C8D
kibuzzard-68929C33: G***; kibuzzard-68929C33
kibuzzard-68929C42: G***; kibuzzard-68929C42
kibuzzard-68929C79: G***; kibuzzard-68929C79
kibuzzard-68929C81: G***; kibuzzard-68929C81
kibuzzard-68929CA4: G***; kibuzzard-68929CA4
kibuzzard-68929CB0: G***; kibuzzard-68929CB0

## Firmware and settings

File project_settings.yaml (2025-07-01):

needs_setup: false

# this is set to the name of your repo during setup, you can change it later on using the rename tool
project_name: constant_current_function_gen 

# this is a list of the production formats that you would like
# honestly only use gerbers, i doubt i will add anything else
# but if you want something custom, implement it and throw in
# a pull request
#not support
production_format: gerber

schematic_output_path: docs/

bom_csv_output_path: docs/BOM/

bom_report_output_path: docs/BOM/

production_file_output_path: pcbs/

# all names will follow the pattern [project_name]name.* 
# these settings just define that name suffix
# the underscore here are purely for readablity of the
# output files so the schematic output file name will be
# project_name_schematic.pdf
schematic_output_name: _schematic

bom_csv_output_name: _bill_of_materials

bom_report_output_name: _bom_report

production_file_output_name: _gerber

# these templates use mustache (https://mustache.github.io/mustache.5.html)
# a logic less templating langauge for templating just about anything
bom_template_path: .github/report_templates/bom_report_template.mustache

erc_report_template_path: .github/report_templates/erc_report_template.mustache

drc_report_template_path: .github/report_templates/drc_report_template.mustache

readme_template_path: .github/report_templates/readme.mustache

# allow the readme to be auto updated using the readme template
dynamic_read_me: true

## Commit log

2025-07-06 added sch
    [current_gen.kicad_pcb, current_gen.kicad_sch, template.kicad_pcb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]
2025-07-06 production files
    [current_gen_bill_of_materials.csv]
2025-07-06 added shunt and rpv
    [current_gen.kicad_sch]
2025-07-07 added some docs
    [current_gen.kicad_sch]
2025-07-16 new current gen design
    [current_gen_class_ab.kicad_pcb, current_gen_class_ab.kicad_sch]
2025-07-22 started to add parts
    [current_gen_class_ab.kicad_sch]
2025-07-22 added parts for resitors and opamps
    [current_gen_class_ab.kicad_sch]
2025-07-23 added rvp
    [current_gen_class_ab.kicad_sch]
2025-08-03 routed main amp
    [current_gen_class_ab.kicad_pcb]
2025-08-03 swapped pins around to suit pcb better
    [current_gen_class_ab.kicad_sch]
2025-08-05 routed power started adding stitching and thermal vias
    [current_gen_class_ab.kicad_pcb]
2025-08-05 updated 50ohm shunt
    [current_gen_class_ab.kicad_sch]
2025-08-06 stitch and slikscreened
    [current_gen_class_ab.kicad_pcb]
2025-08-08 added more to BOM
    [current_gen_class_ab.kicad_sch]
2025-08-08 updated fill zones and fixed some routing
    [current_gen_class_ab.kicad_pcb]
2025-08-10 added REV A of pcb
    [current_gen_class_ab-B_Cu.gbr, current_gen_class_ab-B_Mask.gbr, current_gen_class_ab-B_Paste.gbr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]
